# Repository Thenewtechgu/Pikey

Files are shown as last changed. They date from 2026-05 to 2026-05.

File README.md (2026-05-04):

# Pikey

My verson of a usb rubber ducky that can also be used as a storage device
## The Schematic and board



This is the schematic of the board.

Pikey uses
- RP2350B as the controller and communicater between the chip and the computer
- Flash memory (8mb)
- Micro sd card ( can be used for storage of payload or to be used as a normal flash drive)
- A user configurable Tactile Switch
- A 3 color LED (Red, Blue, Green)



And this is the routed board.

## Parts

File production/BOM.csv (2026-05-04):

Reference | Qty | Value | Name | LCSC Part number
C1,C2,C3,C7 | 4 | 4.7uF | Samsung Electro-Mechanics CL05A475MP5NRNC | C23733
C4,C5,C29 | 3 | 10uF | Samsung Electro-Mechanics CL05A106MP5NUNC | C315248
C6,C8,C9,C10,C11,C12,C13,C14,C15,C16,C17,C18 | 12 | 100uF | Samsung Electro-Mechanics CL05C101JB5NNNC | C26409
C19,C20 | 2 | 15pF | Samsung Electro-Mechanics CL05C150JB5NNNC | C86285
D1 | 1 | SMLVN6RGB | ROHM SMLVN6RGB1U1 | C2909770
D17,D18 | 2 | 5V | onsemi RB521S30T1G | C145179
J2 | 1 | DX07P024MJ1R1500 | JAE Electronics DX07P024MJ1R1500 | C134112
J3 | 1 | Microsd card | HRS DM3AT-SF-PEJM5 | C114218
L2 | 1 | AOTA-B201610S3R3-101-T | ABRACON AOTA-B201610S3R3-101-T | C42411119
R1,R14 | 2 | 5.1kΩ | YAGEO RC0402FR-075K1L | C105872
R2,R3 | 2 | 27Ω | PANASONIC ERJ2RKF27R0X | C413051
R4 | 1 | 33Ω | FOJAN FRC0402F33R0TS | C2906868
R5,R6 | 2 | 1kΩ | YAGEO RC0402FR-071KL | C106235
R7 | 1 | 9.1kΩ | YAGEO RC0402FR-079K1L | C163450
R8 | 1 | 6.2kΩ | YAGEO RC0402FR-076K2L | C137946
R9,R10,R11,R12,R13 | 5 | 10kΩ | YAGEO RC0402FR-0710KL | C60490
S1 | 1 | SKRPACE010 | ALPSALPINE SKRPACE010 | C139797
U1 | 1 | RP2350B | Raspberry Pi RP2350B | C42415655
U2 | 1 | NCP1117-3.3_SOT223 | onsemi NCP1117ST33T3G | C26537
U3 | 1 | W25Q128JVS | Winbond W25Q128JVSIQ | C97521
Y1 | 1 | ABM8-272-T3 | ABRACON ABM8-272-T3 | C20625731

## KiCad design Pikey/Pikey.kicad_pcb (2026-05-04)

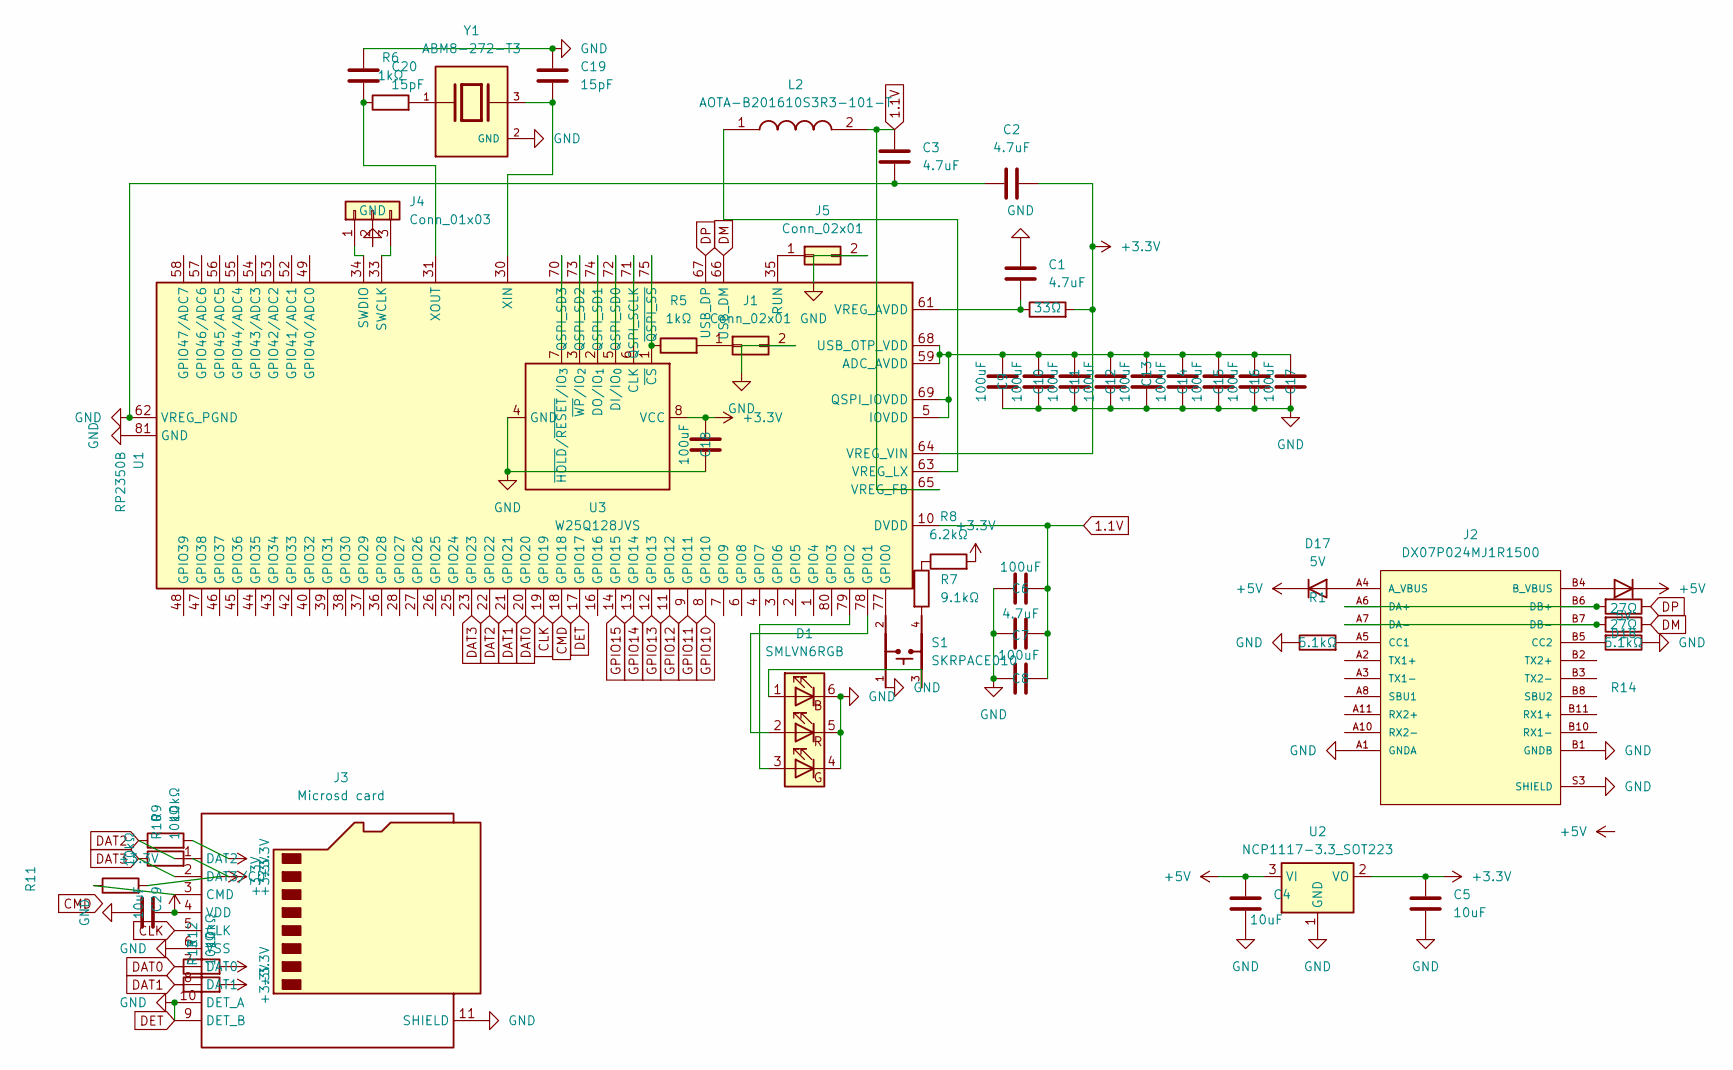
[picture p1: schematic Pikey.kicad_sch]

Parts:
C1, C2, C3, C7: 4.7uF; C_0402_1005Metric; LCSC Part number C23733
C4, C5, C29: 10uF; C_0402_1005Metric; LCSC Part number C315248
C6, C8, C9, C10, C11, C12, C13, C14, C15, C16, C17, C18: 100uF; C_0402_1005Metric; LCSC Part number C26409
C19, C20: 15pF; C_0402_1005Metric; LCSC Part number C86285
D1: SMLVN6RGB; LED_ROHM_SMLVN6; LCSC Part number C2909770
D17, D18: 5V; D_0402_1005Metric; LCSC Part number C145179
J1, J5: Conn_02x01; PinHeader_2x01_P1.00mm_Vertical
J2: DX07P024MJ1R1500; JAE_DX07P024MJ1R1500; PARTREV 1.0; LCSC Part number C134112
J3: Microsd card; microSD_HC_Hirose_DM3AT-SF-PEJM5; LCSC Part number C114218
J4: Conn_01x03; PinHeader_1x03_P1.00mm_Vertical
L2: AOTA-B201610S3R3-101-T; AOTAB201610S3R3101T; Manufacturer_Part_Number AOTA-B201610S3R3-101-T; Mouser Part Number 815-AB201610S3R3101T
R1, R14: 5.1kΩ; R_0201_0603Metric; LCSC Part number C105872
R2, R3: 27Ω; R_0201_0603Metric; LCSC Part number C413051
R4: 33Ω; R_0402_1005Metric; LCSC Part number C2906868
R5, R6: 1kΩ; R_0402_1005Metric; LCSC Part number C106235
R7: 9.1kΩ; R_0201_0603Metric; LCSC Part number C163450
R8: 6.2kΩ; R_0201_0603Metric; LCSC Part number C137946
R9, R10, R11, R12, R13: 10kΩ; R_0201_0603Metric; LCSC Part number C60490
S1: SKRPACE010; SW_SKRPACE010; LCSC Part number C139797
U1: RP2350B; QFN-80-1EP_10x10mm_P0.4mm_EP3.4x3.4mm; LCSC Part number C42415655
U2: NCP1117-3.3_SOT223; SOT-223-3_TabPin2; LCSC Part number C26537
U3: W25Q128JVS; SOIC-8_5.3x5.3mm_P1.27mm; LCSC Part number C97521
Y1: ABM8-272-T3; XTAL_ABM8-272-T3; PARTREV 07-29-20; LCSC Part number C20625731

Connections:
1.1V: C3.1, C6.1, C7.1, C8.1, L2.2, U1.10 (DVDD), U1.32 (DVDD), U1.51 (DVDD), U1.65 (VREG_FB)
+3.3V: C2.1, C5.2, C18.1, C29.1, J3.4 (VDD), R4.2, R8.2, R9.2, R10.2, R11.2, R12.2, R13.2, U1.64 (VREG_VIN), U2.2 (VO), U3.8 (VCC)
+5V: C4.2, D17.1 (K), D18.1 (K), U2.3 (VI)
A_VBUS: D17.2 (A), J2.A4 (A_VBUS), J2.A9 (A_VBUS)
B_VBUS: D18.2 (A), J2.B4 (B_VBUS), J2.B9 (B_VBUS)
CLK: J3.5 (CLK), U1.19 (GPIO19)
DAT0: J3.7 (DAT0), R12.1, U1.20 (GPIO20)
DAT1: J3.8 (DAT1), R13.1, U1.21 (GPIO21)
DAT2: J3.1 (DAT2), R9.1, U1.22 (GPIO22)
DAT3: J3.2 (DAT3/CD), R10.1, U1.23 (GPIO23)
DET: C1.1, C2.2, C3.2, C4.1, C5.1, C6.2, C7.2, C8.2, C9.2, C10.2, C11.2, C12.2, C13.2, C14.2, C15.2, C16.2, C17.2, C18.2, C19.1, C20.1, C29.2, D1.4 (GK), D1.5 (RK), D1.6 (BK), J1.2, J2.A1 (GNDA), J2.A12 (GNDA), J2.B1 (GNDB), J2.B12 (GNDB), J2.S3 (SHIELD), J2.S4 (SHIELD), J2.S5 (SHIELD), J2.S6 (SHIELD), J3.6 (VSS), J3.9 (DET_B), J3.10 (DET_A), J3.11 (SHIELD), J4.2, J5.2, R1.1, R14.1, S1.1, U1.17 (GPIO17), U1.62 (VREG_PGND), U1.81 (GND), U2.1 (GND), U3.4 (GND), Y1.2 (GND), Y1.4 (GND)
DM: R2.1, U1.66 (USB_DM)
DP: R3.1, U1.67 (USB_DP)
GPIO10: U1.8 (GPIO10)
GPIO11: U1.9 (GPIO11)
GPIO12: U1.11 (GPIO12)
GPIO13: U1.12 (GPIO13)
GPIO14: U1.13 (GPIO14)
GPIO15: U1.14 (GPIO15)
unnamed: D1.1 (BA), S1.3
unnamed: D1.3 (GA), U1.79 (GPIO2)
unnamed: D1.2 (RA), U1.78 (GPIO1)
unnamed: J1.1, R5.2
unnamed: J2.A5 (CC1), R1.2
unnamed: J2.B5 (CC2), R14.2
unnamed: J2.A6 (DA+), J2.B6 (DB+), R3.2
unnamed: J2.A7 (DA-), J2.B7 (DB-), R2.2
unnamed: J4.1, U1.34 (SWDIO)
unnamed: J4.3, U1.33 (SWCLK)
unnamed: J5.1, U1.35 (RUN)
unnamed: R6.2, Y1.1
unnamed: R7.1, R8.1
unnamed: R7.2, S1.4
unnamed: C9.1, C10.1, C11.1, C12.1, C13.1, C14.1, C15.1, C16.1, C17.1, U1.5 (IOVDD), U1.15 (IOVDD), U1.24 (IOVDD), U1.29 (IOVDD), U1.41 (IOVDD), U1.50 (IOVDD), U1.59 (ADC_AVDD), U1.60 (IOVDD), U1.68 (USB_OTP_VDD), U1.69 (QSPI_IOVDD), U1.76 (IOVDD)
unnamed: S1.2, U1.77 (GPIO0)
unnamed: U1.71 (QSPI_SCLK), U3.6 (CLK)
unnamed: U1.72 (QSPI_SD0), U3.5 (DI/IO_{0})
unnamed: U1.74 (QSPI_SD1), U3.2 (DO/IO_{1})
unnamed: U1.73 (QSPI_SD2), U3.3 (~WP/IO_{2})
unnamed: U1.70 (QSPI_SD3), U3.7 (~HOLD/~RESET/IO_{3})
unnamed: C1.2, R4.1, U1.61 (VREG_AVDD)
unnamed: L2.1, U1.63 (VREG_LX)
unnamed: C19.2, U1.30 (XIN), Y1.3
unnamed: C20.2, R6.1, U1.31 (XOUT)
unnamed: R5.1, U1.75 (~QSPI_SS), U3.1 (~CS)

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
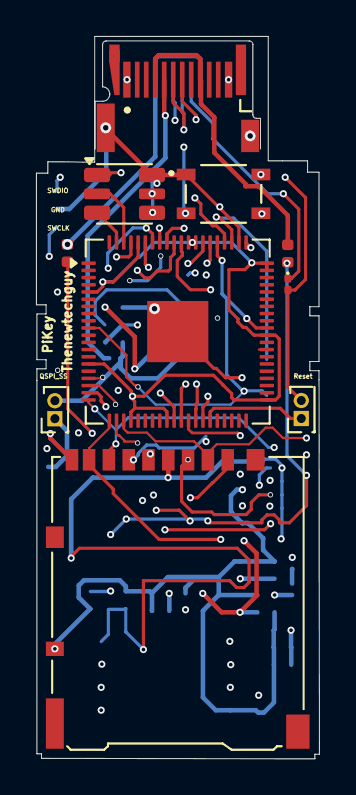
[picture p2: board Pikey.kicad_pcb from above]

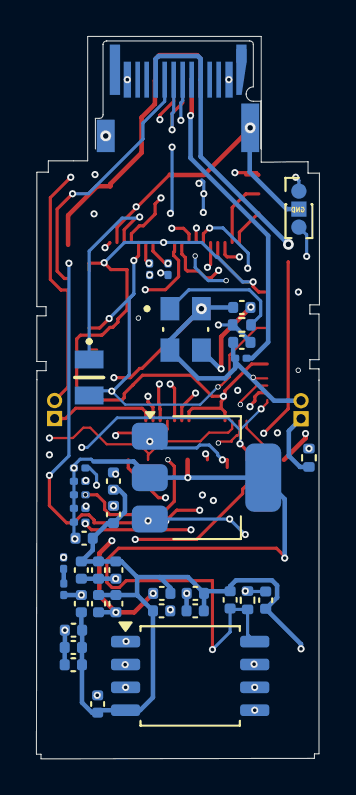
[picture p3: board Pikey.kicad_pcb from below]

Board: 4 copper layers, 15.7 x 40.1 mm, 49 parts (39 on the bottom side), 40 nets.

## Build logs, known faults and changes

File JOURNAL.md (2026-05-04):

# Friday 10th April:


After 30 minutes of searching I have finally found a usb-c male connector that has a Kicad library and is on LCSC



Time spent: 0.67 hours

# Saturday 11th April: 
RP2350B required parts
(Following the RP2350B design guide btw)

Voltage regulator



USB-C power supply



Power filtering/ Decoupling capacitors for the RP2350B



While working on the 9 capacitors I kept running inot the issue of not being able to connect the pins together, then I looked closer and saw that they were slightly misaligned so I tried moving one side up but it didn't work so I just did the whole row again:> (Too lazy to find the problem:/)

Flash memory



The pins for the Rp2350B's and on the W25Q128JVS line up!

Crystal Oscillator



Debug connector



I modified the footprint of a 1x3 pin header for it to be SMD

Reset and others





I want to be able to not turn my computer into a virus so i need a button and a status light 

Time spent: 1.25 hours

# Sunday 12th April:

Sd card holder:

Since I want this to be a normal USB drive as well so I need a sd card slot because nand is too expensive 


Time spent: 0.3 hour

# Monday 13th April


I added a bluetooth moudle so the key can be a sitting duck and the payload can be activated remotely
This took the longest time because of its complexity 
Time spent: 0.834 hours

# Tuesday 14th April

Time spent: 0.67 hour

Making the BOM file
So I want to make sure before I move on that all the parts needed are avalible so that I dont lose time redesigning.



All done!!



Opps


Wrong code:))



THAT'S IS BIG I MIGHT RECONSIDER REMOVING THE BLUETOOTH CHIP FOR MONEY SAKE. ( A PROBLEM FOR ADAM OF TOMOROW)

# Monday 20th April
My midterms are done so it's time to finish this!

I've decided to remove the bluetooth chip all together because of the space needed for the ant that Pikey wont have if I want this to be a small footprint device


Time spent: 0.084 hours
Byebye for now

# Monday 27th April



I have finished placing all the components. Now whats left is to route and design a case of it.

Time spent: 0.75 hours

# Tuesday 28th April


Updating Kicad made me lose progress:(((

Routing the board



My progress rn

Time spent: 55 minutes

# Wednesday 29th April 



Wiring completed!!!



Just this to deal with this before 3d modeling!

Most of the DRC error was because of the vias but I check JLCPCB's abilities and procceded

So I made some cutouts for a case



Time spent: 1.75 hours

# Thursday 30th April


I just found out that the usb c connector I was using is a slide in connector:(( So I have to use a new one (DX07P024MJ1R1500)

Also from looking at the 3d render of the board





I realised that there are so much free space so I want to make the board smaller so I'm going to be replacing and re-routing the board.

Time spent: 10 minutes

# Friday 1st May
Redesigning the board


I made the board to tight:((. Have to redo:/



Hopefully 3rd time goes well

Time spent: 2.3 hours

# Saturday 2nd May


All done!!!



(Had to change some the pins connected to the SD card reader so that it connects)

Added some text and a QR code to the Github page




Time spent 3 hours

# Monday 4th May 

Updated Readme and uploaded the production files.

(For making the requirment for this journal I'm just gonna put a photo of the schematic)



Time spent 0.2 hours

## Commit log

2026-04-10 Add journal entry for usb-c connector search
    Documented the search for a usb-c male connector with Kicad library.
2026-04-11 Update JOURNAL.md with RP2350B component details
    Added detailed notes and images for components related to the RP2350B project, including voltage regulator, USB-C power supply, capacitors, flash memory, crystal oscillator, debug connector, and reset.
2026-04-11 11th April 2026 update
    [Pikey.kicad_pcb, Pikey.kicad_sch]
2026-04-12 Revise JOURNAL.md with new entries and images
    Updated journal entries with images and additional details for various components including voltage regulator, USB-C power supply, and sd card holder.
2026-04-13 13th April update
    added the nRF8001
    [Pikey.kicad_sch]
2026-04-14 Update JOURNAL.md with BOM file creation details
    Documented the process of creating the BOM file and noted issues encountered.
2026-04-20 20th april update
    [Pikey.csv, Pikey.kicad_pcb, Pikey.kicad_sch]
2026-05-02 May 2nd update
    [Pikey.kicad_pcb, Pikey.kicad_sch, bom.csv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]
2026-05-04 Enhance README with project details and schematics
    Expanded project description and added schematic details.
2026-05-04 Monday 4th May update
    [BOM.csv, Pikey.kicad_pcb, Pikey.kicad_sch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]
